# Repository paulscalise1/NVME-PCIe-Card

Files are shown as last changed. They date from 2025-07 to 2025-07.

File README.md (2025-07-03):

# NVME PCIe Card

A x4 PCIe to NVME adapter card for additional storage in PCIe Gen 4 and below compatable machines.
This board was created for the final project in ECEN 882 Passive Microwave Components at the University of Nebraska-Lincoln.

board

## PCB Design
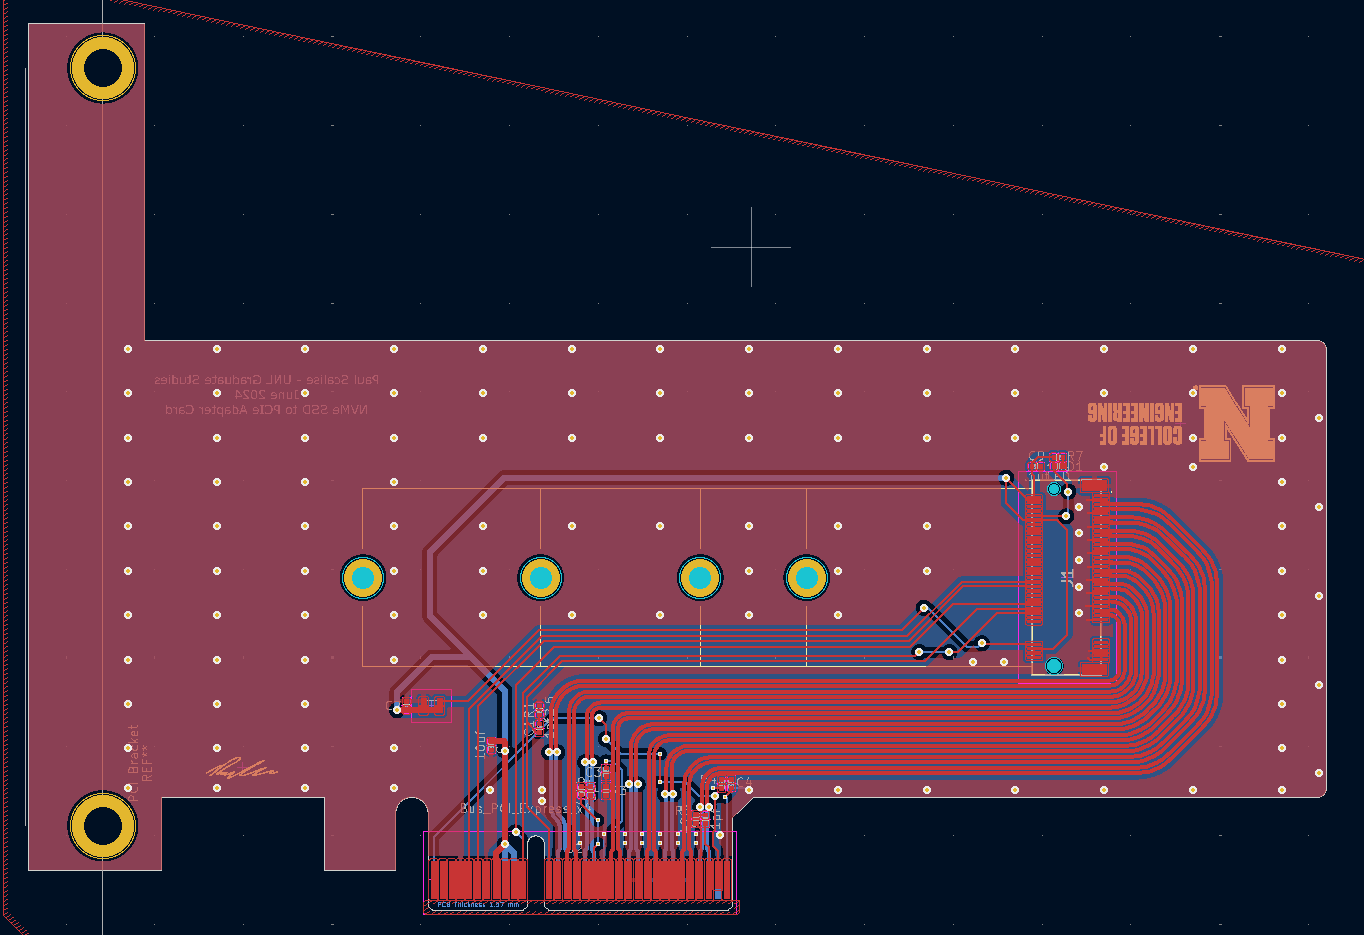
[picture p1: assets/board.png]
pcb


## Validation

This board was tested with and on PCIe Gen 3 capable hardware. Read and write speeds top out near the real world limits of the hardware, thus proving at least PCIe Gen 3 performance metrics.
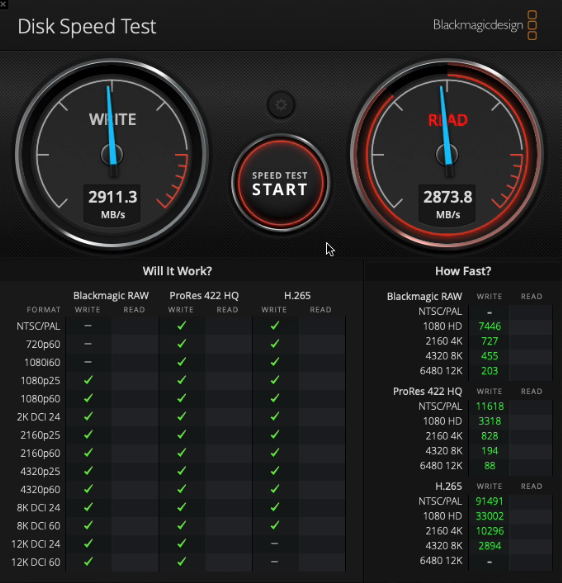
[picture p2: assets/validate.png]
valid


## TODO
Need to add full BOM.

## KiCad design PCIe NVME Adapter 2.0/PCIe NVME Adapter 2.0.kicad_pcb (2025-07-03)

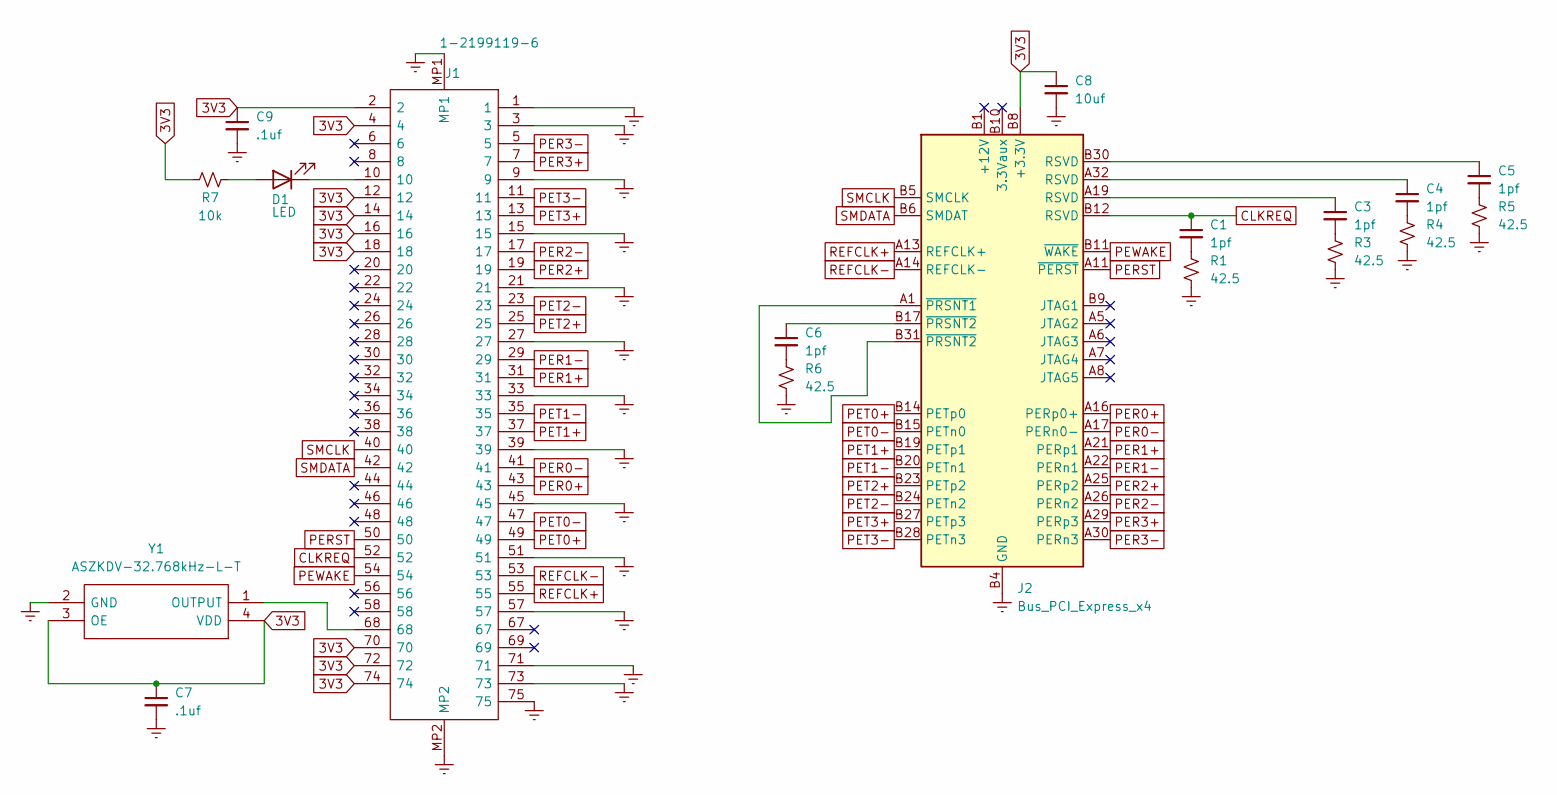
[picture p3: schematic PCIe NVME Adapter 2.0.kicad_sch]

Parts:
C1, C3, C4, C5, C6: 1pf; C_0402_1005Metric
C7, C9: .1uf; C_0402_1005Metric
C8: 10uf; C_0402_1005Metric
D1: LED; LED_0402_1005Metric
J1: 1-2199119-6; 121991196; Mouser Part Number 571-1-2199119-6
J2: Bus_PCI_Express_x4; BUS_PCIexpress_x4
R1, R3, R4, R5, R6: 42.5; R_0402_1005Metric
R7: 10k; R_0402_1005Metric
Y1: ASZKDV-32.768kHz-L-T; ASZKDV32768kHzLT; Mouser Part Number 815-ASZKDV32768KHZLT

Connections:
3V3: C7.1, C8.1, C9.1, J1.2, J1.4, J1.12, J1.14, J1.16, J1.18, J1.70, J1.72, J1.74, J2.A9 (+3.3V), J2.A10 (+3.3V), J2.B8 (+3.3V), R7.1, Y1.3 (OE), Y1.4 (VDD)
CLKREQ: C1.1, J1.52, J2.B12 (RSVD)
Earth: C7.2, C8.2, C9.2, J1.1, J1.3, J1.9, J1.15, J1.21, J1.27, J1.33, J1.39, J1.45, J1.51, J1.57, J1.71, J1.73, J1.75, J1.MP1, J1.MP2, J2.A4 (GND), J2.A12 (GND), J2.A15 (GND), J2.A18 (GND), J2.A20 (GND), J2.A23 (GND), J2.A24 (GND), J2.A27 (GND), J2.A28 (GND), J2.A31 (GND), J2.B4 (GND), J2.B7 (GND), J2.B13 (GND), J2.B16 (GND), J2.B18 (GND), J2.B21 (GND), J2.B22 (GND), J2.B25 (GND), J2.B26 (GND), J2.B29 (GND), J2.B32 (GND), R1.2, R3.2, R4.2, R5.2, R6.2, Y1.2 (GND)
unnamed: C1.2, R1.1
unnamed: C3.1, J2.A19 (RSVD)
unnamed: C3.2, R3.1
unnamed: C4.1, J2.A32 (RSVD)
unnamed: C4.2, R4.1
unnamed: C5.1, J2.B30 (RSVD)
unnamed: C5.2, R5.1
unnamed: C6.1, J2.B17 (~PRSNT2)
unnamed: C6.2, R6.1
unnamed: D1.2 (A), R7.2
unnamed: D1.1 (K), J1.10
unnamed: J2.A1 (~PRSNT1), J2.B31 (~PRSNT2)
unnamed: J1.68, Y1.1 (OUTPUT)
PER0+: J1.43, J2.A16 (PERp0+)
PER0-: J1.41, J2.A17 (PERn0-)
PER1+: J1.31, J2.A21 (PERp1)
PER1-: J1.29, J2.A22 (PERn1)
PER2+: J1.19, J2.A25 (PERp2)
PER2-: J1.17, J2.A26 (PERn2)
PER3+: J1.7, J2.A29 (PERp3)
PER3-: J1.5, J2.A30 (PERn3)
PERST: J1.50, J2.A11 (~PERST)
PET0+: J1.49, J2.B14 (PETp0)
PET0-: J1.47, J2.B15 (PETn0)
PET1+: J1.37, J2.B19 (PETp1)
PET1-: J1.35, J2.B20 (PETn1)
PET2+: J1.25, J2.B23 (PETp2)
PET2-: J1.23, J2.B24 (PETn2)
PET3+: J1.13, J2.B27 (PETp3)
PET3-: J1.11, J2.B28 (PETn3)
PEWAKE: J1.54, J2.B11 (~WAKE)
REFCLK+: J1.55, J2.A13 (REFCLK+)
REFCLK-: J1.53, J2.A14 (REFCLK-)
SMCLK: J1.40, J2.B5 (SMCLK)
SMDATA: J1.42, J2.B6 (SMDAT)

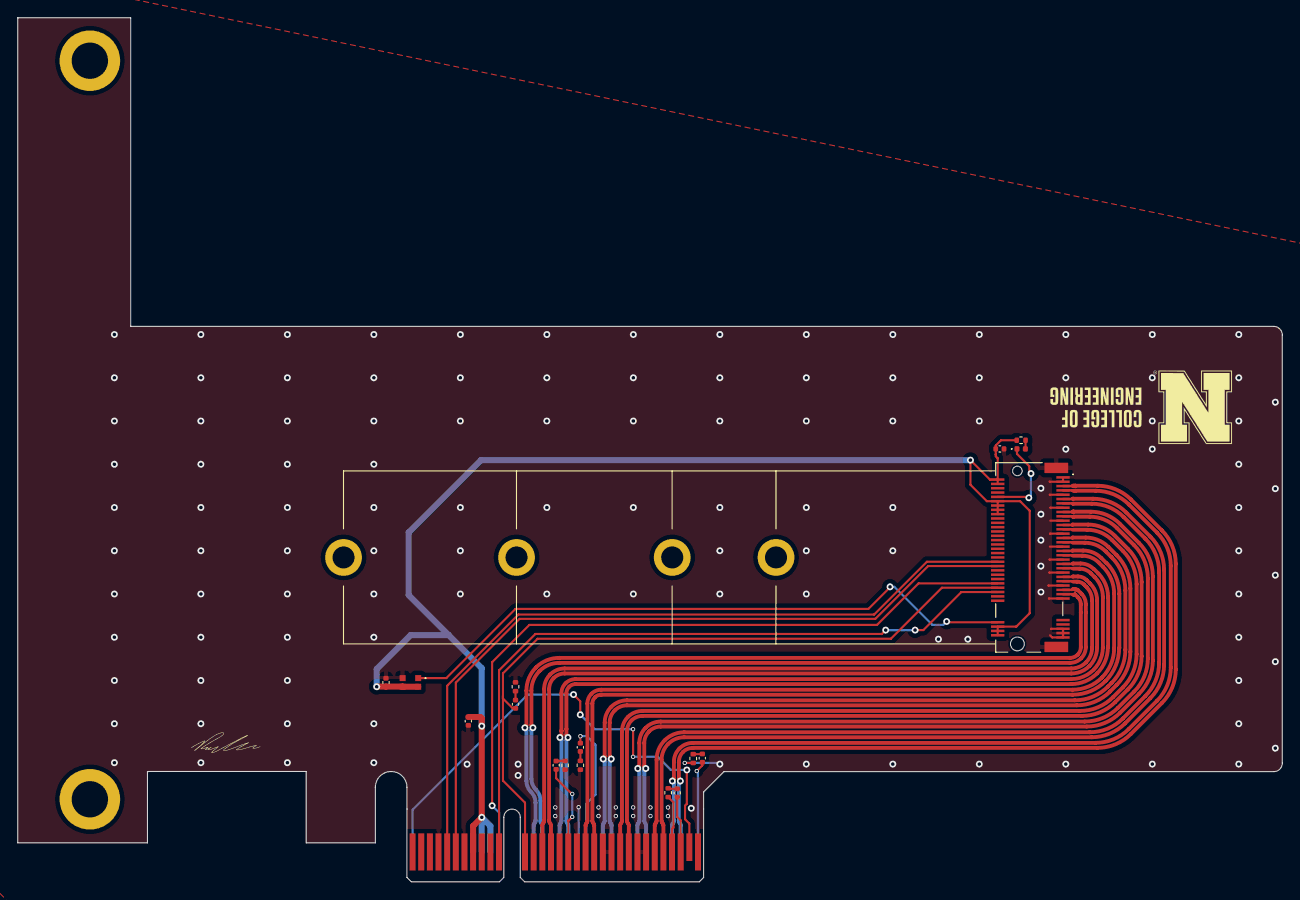
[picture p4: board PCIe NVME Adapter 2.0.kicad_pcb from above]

Board: 2 copper layers, 146.2 x 99.9 mm, 18 parts (0 on the bottom side), 38 nets.
